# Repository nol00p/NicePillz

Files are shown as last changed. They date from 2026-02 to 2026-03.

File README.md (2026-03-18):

# NicePillz
this is a pillzmod pcb reworked to be dedicated to the nice!nano

Changes include:
- moved the register to the high frequency pins
- Terminal blocks for easy install of the battery and power switch
- moved col0 directly to the nice!nano so the keyboard can wake up by pressing the top ESC key.

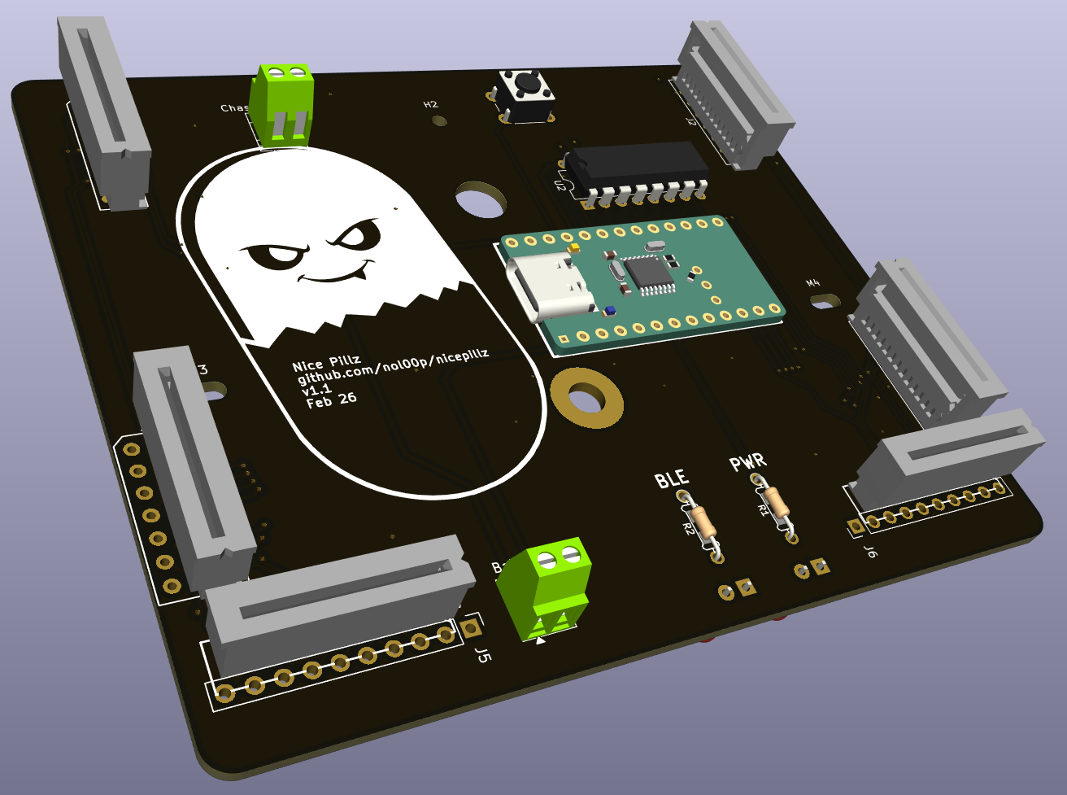
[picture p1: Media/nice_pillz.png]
board


## Bill of materials

| Position | Description | Qty | Notes |
| --- | --- | --- | --- |
| J1–J8 | Molex 39-53-2135 | 6 | [Mouser](https://eu.mouser.com/ProductDetail/Molex/39-53-2135?qs=cm0cgiBciNYI3jeMaEn0Ng%3D%3D) |
| | LED | 2 | [Amazon](https://www.amazon.fr/dp/B005Q2MZ4Q) |
| ble-pwr | 10k resistor | 2 | Affects LED brightness. Smaller = brighter |
| U2 | 74HC595 | 1 | [Amazon](https://www.amazon.fr/dp/B093Y2MQGV) |
| U2 | 16-pin IC socket | 1 | [Amazon](https://www.amazon.fr/dp/B07ZCRTRXK?ref=ppx_yo2ov_dt_b_fed_asin_title&th=1) |
| | Terminals | 3 | [AliExpress](https://fr.aliexpress.com/item/1005006589335718.html)  |
| | reset button | 1 | [AliExpress](https://fr.aliexpress.com/item/1005007623070623.html)  |
| | Power button | 1 | [Amazon](https://www.amazon.fr/dp/B08L484J7W) |
| | Nice!Nano | 1 | |
| | 3.7V battery - 2000mAh | 1 | [Amazon](https://www.amazon.fr/dp/B08214DJLJ) |
| | USB-C panel mount| 1 | [AliExpress](https://fr.aliexpress.com/item/1005009401577622.html) |

## Assembly
Assembly is very straight forward

LED: the trickiest part might be the LED, make sure to first drop them on the chassi pockets and solder them when in place. 
note the short leg goes to the square pad. 

terminal: when installing the terminal make sure they are facing outward so the little arrow indicated the positive wire. 

## ZMK
see: https://github.com/nol00p/ZMK-NicePillz

## Attribution
This project is a fork of https://github.com/dcpedit/pillzmod

## Thumbcluster
Next the Thumbcluster, the plan here is to use the same terminal to be able to reuse the ribbon cables. and include hot swap sockets. Get in touch if that is something of interest.

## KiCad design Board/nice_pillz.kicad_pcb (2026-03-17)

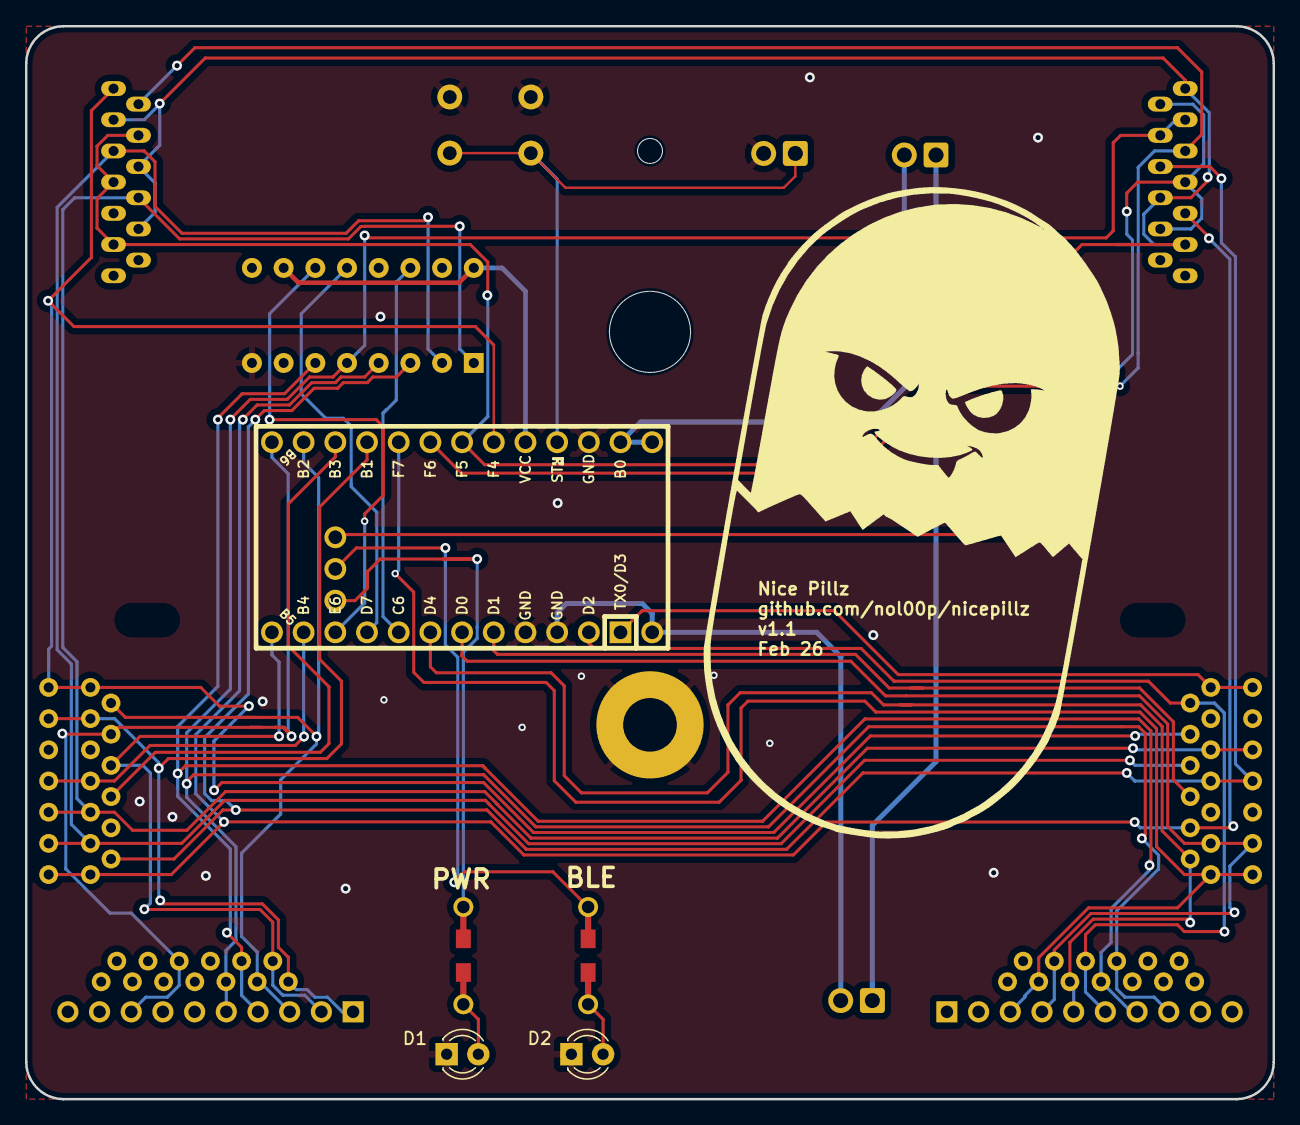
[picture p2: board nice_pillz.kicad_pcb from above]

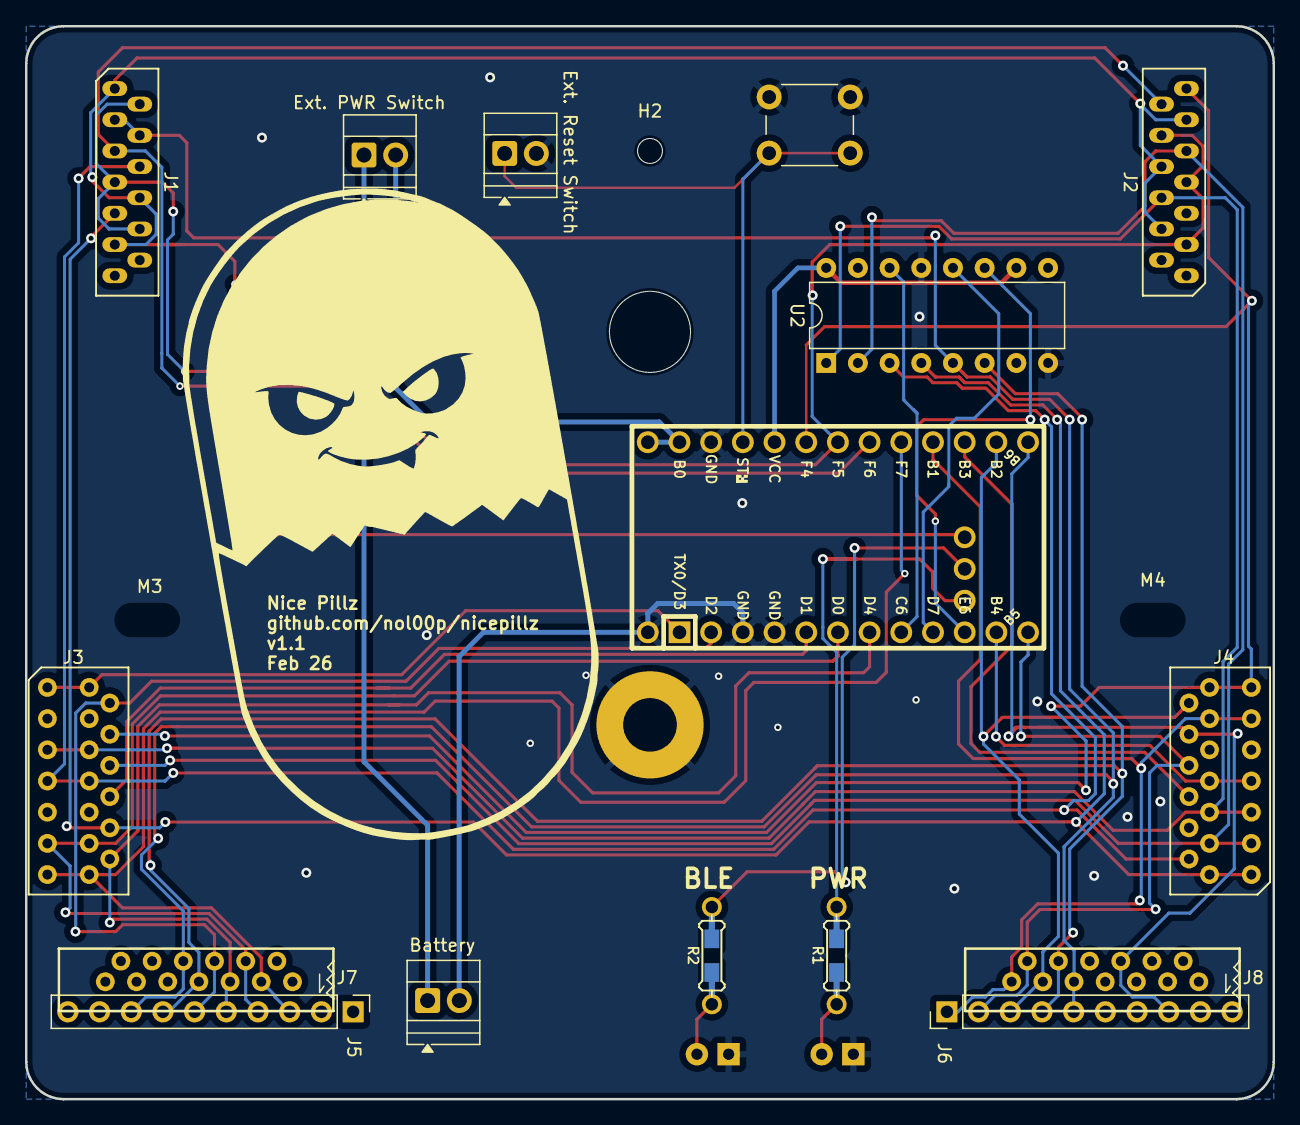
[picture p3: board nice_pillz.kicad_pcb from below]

Board: 2 copper layers, 100.0 x 86.0 mm, 22 parts (19 on the bottom side), 34 nets.

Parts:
Battery: TerminalBlock_Xinya_XY308-2.54-2P_1x02_P2.54mm_Ho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; TerminalBlock_Xinya_XY308-2.54-2P_1x02_P2.54mm_Horizontal
D1: LED_CAPS; LED_D3.0mm
D2: LED_NUM; LED_D3.0mm
Ext. PWR Switch, Ext. Reset Switch: TerminalBlock_Xinya_XY308-2.54-2P_1x02_P2.54mm_Ho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; TerminalBlock_Xinya_XY308-2.54-2P_1x02_P2.54mm_Horizontal
H1: mounting pad; MountingHole_4.3mm_M4_Pad
H2: mounting pad; MountingHole_2mm
J1, J2: Conn_01x13; Molex_0039532135
J3, J4: Conn_01x13; Molex_039532134
J5, J6: Conn_01x10; Pin_Header_Straight_1x10_Pitch2.54mm
J7, J8: Conn_01x13; 39-53-2135
M1: MountingHole_6.4mm_M6
M3, M4: MountingHole_4.3mm_M4
R1, R2: R_US; Resistor-Hybrid
U1: nice!nanov2; nice_nano_v2
U2: 74HC595; DIP-16_W7.62mm

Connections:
+5V: U1.21 (VCC), U2.10 (~SRCLR), U2.16 (VCC)
/COL_0: J2.13, J3.4, J4.13, U1.20 (A3/PF4)
/COL_1: J2.6, J3.5, J4.5, U2.1 (QB)
/COL_2: J2.9, J3.6, J4.3, U2.2 (QC)
/COL_3: J1.6, J3.7, J4.2, U2.3 (QD)
/COL_4: J1.9, J3.10, J4.1, U2.4 (QE)
/COL_5: J1.3, J1.4, J5.8, J6.5, J7.8, J8.9, U2.5 (QF)
/COL_6: J5.7, J6.4, J7.7, J8.10, U2.6 (QG)
/LATCH: U1.9 (6/PD7), U2.12 (RCLK)
/LED_CAPS_LOCK: R1.2, U1.26 (D5)
/LED_NUM_LOCK: R2.2, U1.27 (C7)
/RESET: Ext. Reset Switch.1, U1.22 (RST)
/ROW_0: J4.6, U1.15 (14/PB3)
/ROW_1: J4.7, U1.11 (8/PB4)
/ROW_2: J4.8, J6.2, J8.12, U1.12 (9/PB5)
/ROW_3: J4.10, J6.8, J8.6, U1.13 (10/PB6)
/ROW_4: J4.11, J6.1, J8.13, U1.16 (15/PB1)
/ROW_5: J4.12, J6.3, J8.11, U1.14 (16/PB2)
/ROW_6: J3.13, J5.3, J7.3, U1.17 (A0/PF7)
/ROW_7: J3.11, J5.4, J7.4, U1.6 (3/PD0)
/ROW_8: J3.12, J5.5, J7.5, U1.7 (4/PD4)
/ROW_9: J3.2, J5.6, J7.6, U1.2 (RX1/PD2)
/ROW_10: J3.1, U1.1 (TX0/PD3)
/ROW_11: J3.8, U1.5 (2/PD1)
/ROW_12: J1.5, J2.12, U1.18 (A1/PF6)
/ROW_13: J1.1, J1.8, J1.11, J2.4, J2.8, J2.11, U1.28 (F1)
/ROW_14: J1.2, J1.7, J1.10, J2.3, J2.7, J2.10, U1.19 (A2/PF5)
/SPI_MOSI: U1.8 (5/PC6), U2.14 (SER)
/SPI_SCK: U1.10 (7/PE6), U2.11 (SRCLK)
BAT: Ext. PWR Switch.2, U1.24 (B0)
BAT+: Battery.1, Ext. PWR Switch.1
GND: D1.1 (K), D2.1 (K), Ext. Reset Switch.2, H1.1, U1.3 (GND), U1.4 (GND), U1.23 (GND), U2.8 (GND), U2.13 (~OE)
unnamed: D1.2 (A), R1.1
unnamed: D2.2 (A), R2.1

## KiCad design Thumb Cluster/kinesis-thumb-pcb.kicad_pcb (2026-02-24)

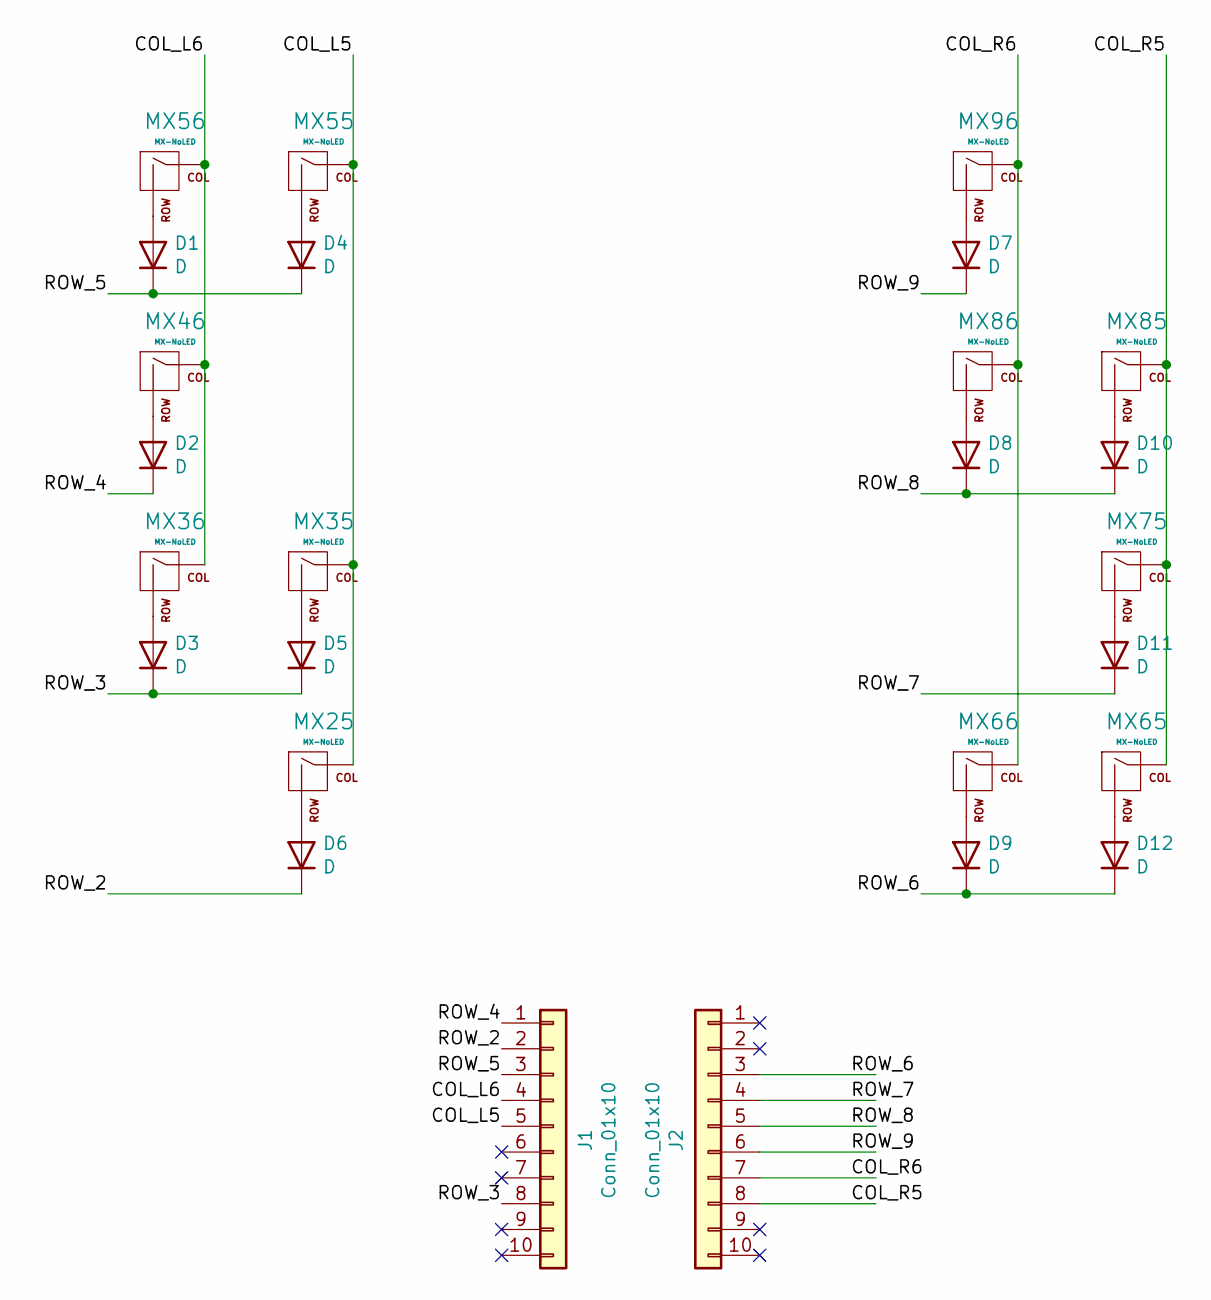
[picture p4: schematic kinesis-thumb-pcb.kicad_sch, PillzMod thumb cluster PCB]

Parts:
D1, D2, D3, D4, D5, D6, D7, D8, D9, D10, D11, D12: D; D_SOD-323_HandSoldering
J1, J2: Conn_01x10; Pin_Header_Straight_1x10_Pitch2.54mm
MX25, MX35, MX36, MX46, MX55, MX56, MX65, MX66, MX75, MX85, MX86, MX96: MX-NoLED

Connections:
/COL_L5: J1.5, MX25.1 (COL), MX35.1 (COL), MX55.1 (COL)
/COL_L6: J1.4, MX36.1 (COL), MX46.1 (COL), MX56.1 (COL)
/COL_R5: J2.8, MX65.1 (COL), MX75.1 (COL), MX85.1 (COL)
/COL_R6: J2.7, MX66.1 (COL), MX86.1 (COL), MX96.1 (COL)
/ROW_2: D6.1 (K), J1.2
/ROW_3: D3.1 (K), D5.1 (K), J1.8
/ROW_4: D2.1 (K), J1.1
/ROW_5: D1.1 (K), D4.1 (K), J1.3
/ROW_6: D9.1 (K), D12.1 (K), J2.3
/ROW_7: D11.1 (K), J2.4
/ROW_8: D8.1 (K), D10.1 (K), J2.5
/ROW_9: D7.1 (K), J2.6
unnamed: D1.2 (A), MX56.2 (ROW)
unnamed: D2.2 (A), MX46.2 (ROW)
unnamed: D3.2 (A), MX36.2 (ROW)
unnamed: D4.2 (A), MX55.2 (ROW)
unnamed: D5.2 (A), MX35.2 (ROW)
unnamed: D6.2 (A), MX25.2 (ROW)
unnamed: D7.2 (A), MX96.2 (ROW)
unnamed: D8.2 (A), MX86.2 (ROW)
unnamed: D9.2 (A), MX66.2 (ROW)
unnamed: D10.2 (A), MX85.2 (ROW)
unnamed: D11.2 (A), MX75.2 (ROW)
unnamed: D12.2 (A), MX65.2 (ROW)

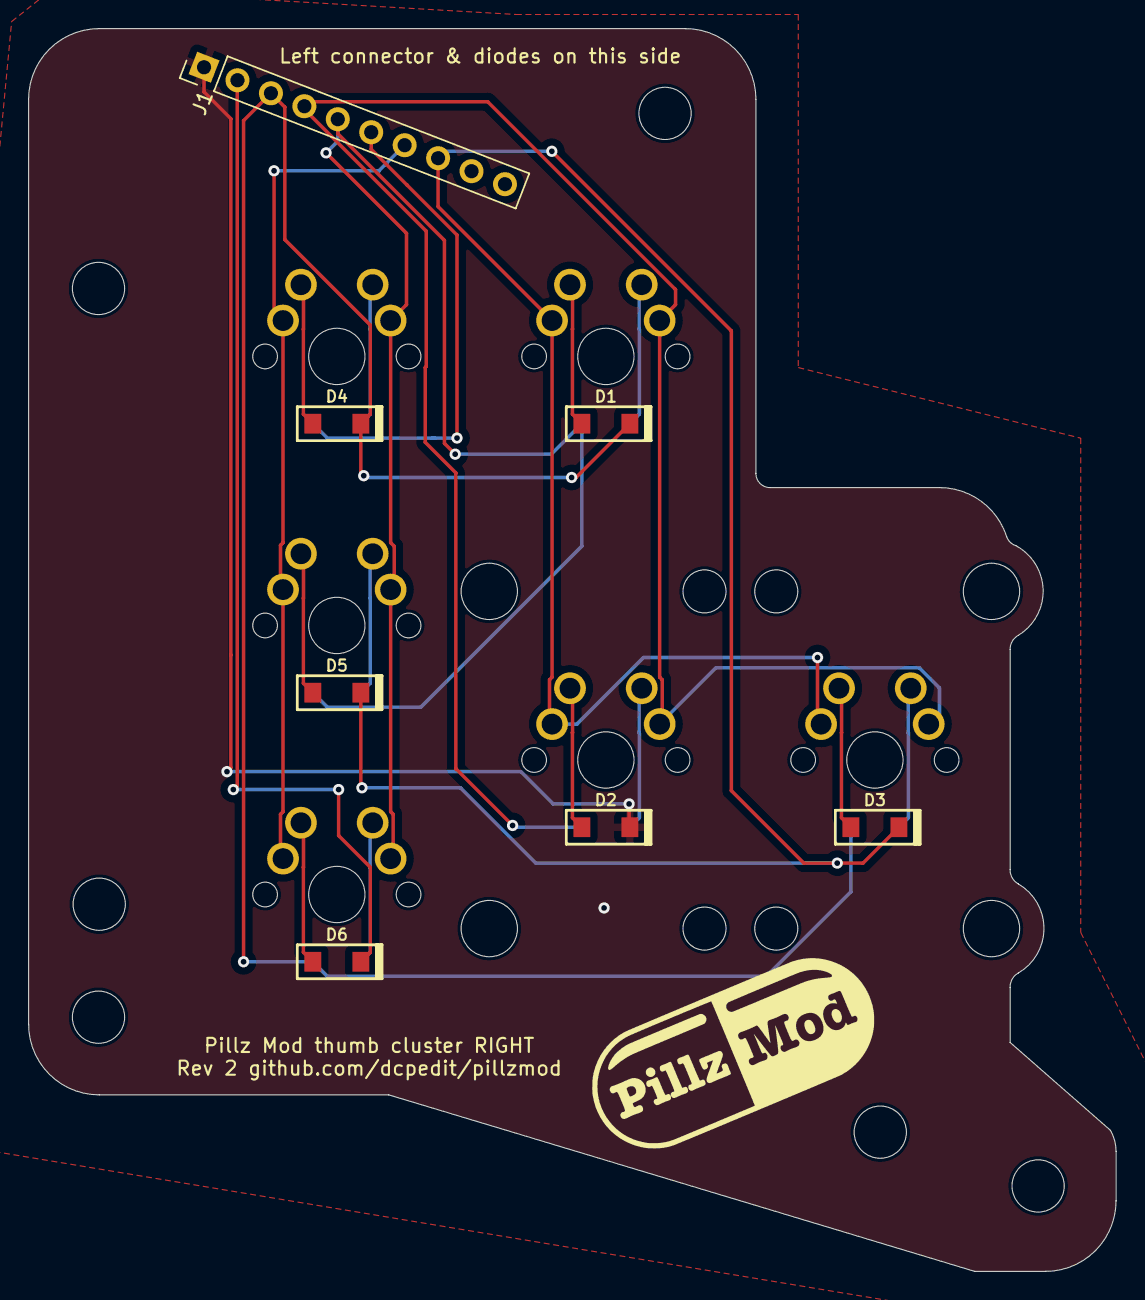
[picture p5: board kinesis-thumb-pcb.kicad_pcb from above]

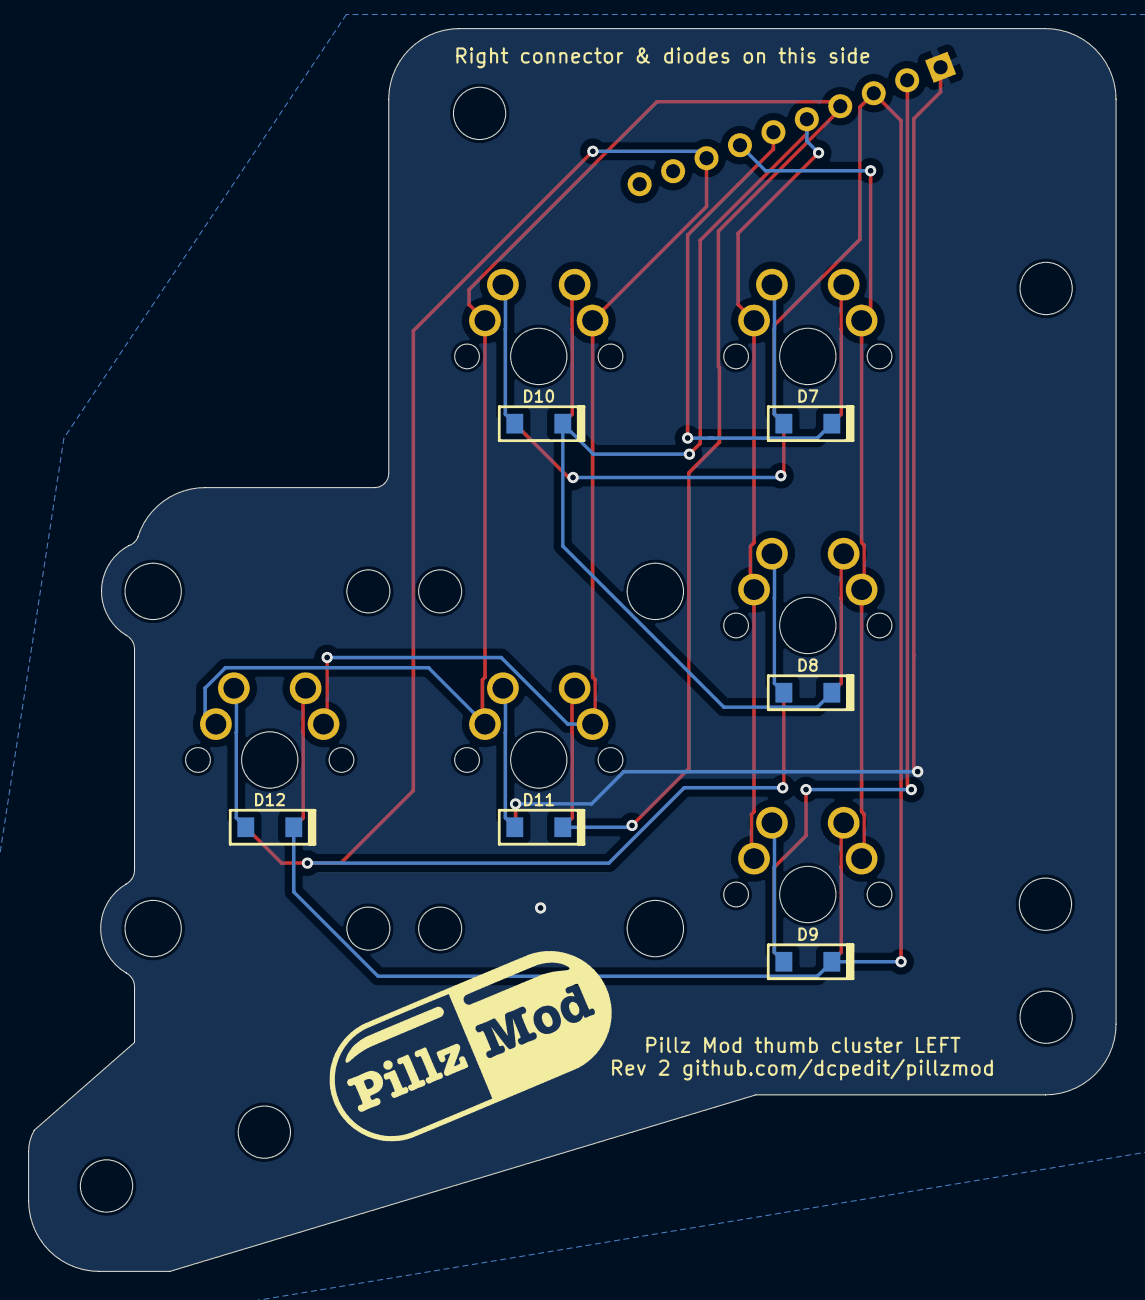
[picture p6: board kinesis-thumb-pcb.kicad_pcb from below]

Board: 2 copper layers, 77.0 x 88.0 mm, 31 parts (18 on the bottom side), 22 nets.

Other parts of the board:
REF1, REF2, REF3, REF4, REF5, REF6: MountingHole_3.7mm

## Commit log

2026-02-14 git init
    [nice_pillz.kicad_pcb, nice_pillz.kicad_sch]
2026-02-16 full update
    [nice_pillz.kicad_pcb, nice_pillz.kicad_sch]
2026-02-16 update 3d
    [nice_pillz.kicad_pcb]
2026-02-16 battery connection
    [nice_pillz.kicad_pcb]
2026-02-20 Production files created
    [nice_pillz-B_Cu.gbl, nice_pillz-B_Mask.gbs, nice_pillz-B_Paste.gbp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]
2026-02-23 folder structure and firmware
    [nice_pillz-B_Cu.gbl, nice_pillz-B_Mask.gbs, nice_pillz-B_Paste.gbp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]
2026-02-23 v1.1 new pcb and overlay config
    [nice_pillz.kicad_pcb, nice_pillz.kicad_sch]
2026-02-24 note update
    [Left_thumb.kicad_pcb, kinesis-thumb-pcb.kicad_pcb, kinesis-thumb-pcb.kicad_sch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]
2026-03-16 firmware upadate
    [nice_pillz-B_Cu.gbl, nice_pillz-B_Mask.gbs, nice_pillz-B_Paste.gbp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]
2026-03-17 documenation update
    [nice_pillz.kicad_pcb]
2026-03-17 clean up
    [nice_pillz-B_Cu.gbl, nice_pillz-B_Mask.gbs, nice_pillz-B_Paste.gbp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]
2026-03-18 updated BOM
